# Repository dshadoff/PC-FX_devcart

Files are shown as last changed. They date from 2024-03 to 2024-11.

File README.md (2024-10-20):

# PC-FX_devcart

This is a design of a development cart for the PC-FX, based almost entirely on the
RP2040 microcontroller.

##  Current Board Revision

The current version is Ver2_RevB.
[(For the Protoype board using an Olimex RP2040-Pico30 module, please click here.)](PC_board/README_prototype.md)

The only changes from RevA to Rev B are related to schematic annotations, and a minor labelling update on the PC
Board itself, so the picture of RevA is included here.

In future, there are plans for a proper 3D printed case.

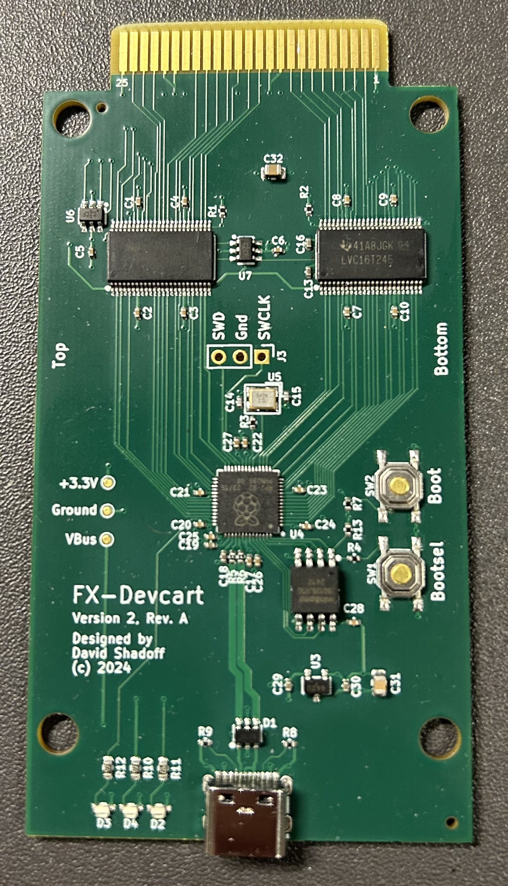
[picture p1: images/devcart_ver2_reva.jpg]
Prototype Board


## Genesis of the Project

The basis of the FX-BMP cartridge is that it consists of 128KB of memory, and the PC-FX can
actually boot from the cartridge memory under the right circumstances.

The FX-BMP memory doesn't need to be very fast - the bus access speed is cut in half when
accessing the FX-BMP range of memory. Assuming that the CPU reads the data at the rising
edge of /OE, this can be as slow as 174ns after /OE. (My design targets have been to keep this
turnaround time below 150ns).

The RP2040 has two CPU cores, and very fast GPIO access. It seemed possible to emply one
CPU core to deal with external access to the memory - emulating a SRAM bus interface - and
for the other CPU core to be used as a supervisor, allowing USB commands to read/write this
memory, downloading programs and preparing them to be booted from.

## Theory of Operation

### Signal Timing - Read

At 21MHz, you would expect the PC-FX to have a very fast bus access speed, however accesses to
the FX-BMP port are apparently clocked at half-speed (and are only 8 bits wide).

In general, bus accesses progress through the following steps for a read cycle:
- Address lines are set up
- /CE transitions low
- /OE transitions low
- The device being queried needs to ready the data, and output it onto the data bus
- /OE transitions high
- The device being queried needs to de-assert/tri-state its outputs
- /CE transitions high

While this is the normal situation, there can also be cases where the /CE line does not return to
high state before a subsequent address setup and corresponding /OE (or /WE) transition to low.

As our circuit operates at 3.3V, keep in mind that good-quality level-shifters will delay incoming
signals by roughly 5ns before they appear, and an additional 10ns on the return path, reducing the
available turnaround time for a read transaction.

Here is a visual of the actual timing of those sequences:

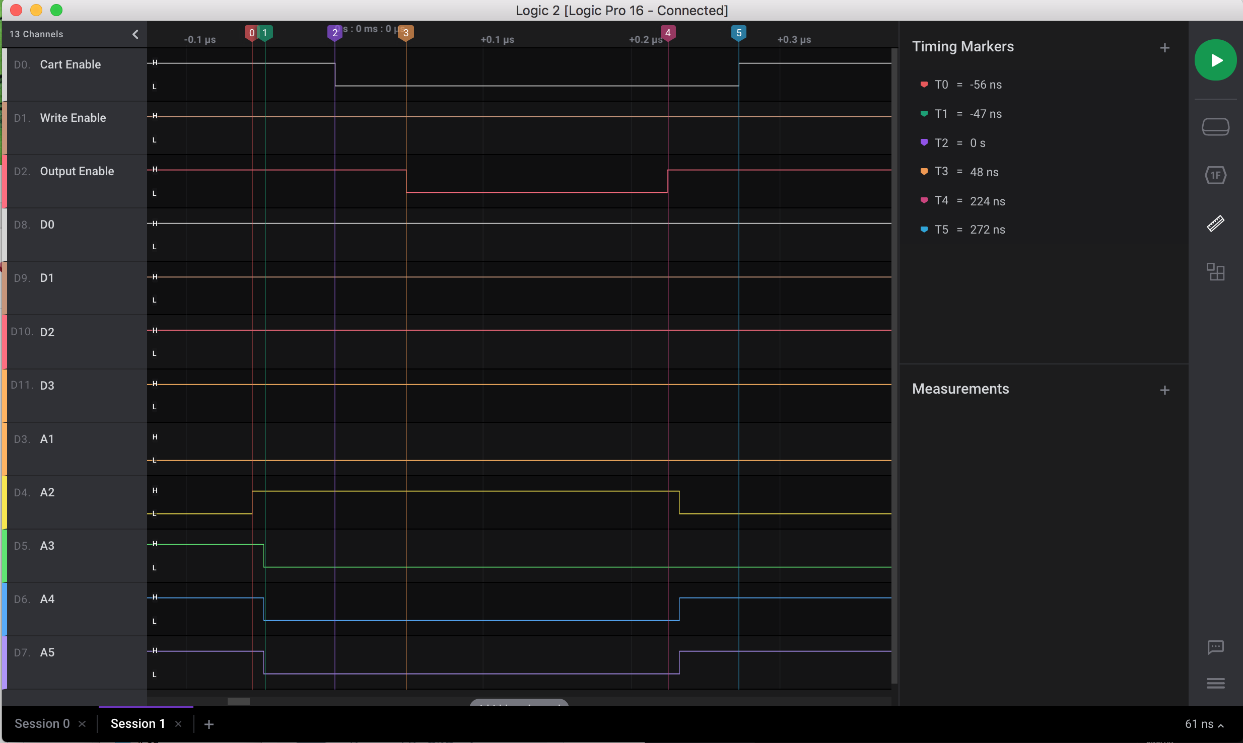
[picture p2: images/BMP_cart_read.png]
Read Cycle Timing


### Signal Timing - Write

In general, bus accesses progress through the following steps for a write cycle:
- Address lines are set up
- /CE transitions low
- /WE transitions low
- Data appears on the bus, to be written to the addressed device (not before /WE !)
- /WE transitions high
- In theory, the written-to device should latch data at this monment, but we can't react that fast, so we will latch earlier
- /CE transitions high

While this is the normal situation, there can also be cases where the /CE line does not returns to
high state before a subsequent address setup and corresponding /WE (or /OE) transition to low.

Here is a visual of the actual timing of those sequences:

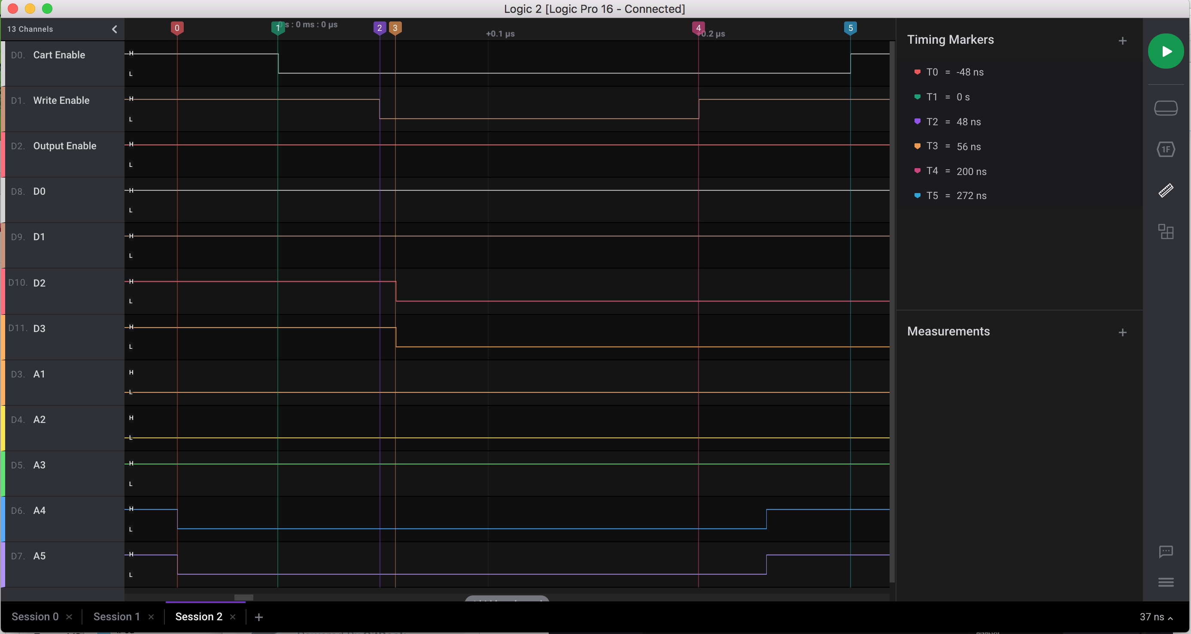
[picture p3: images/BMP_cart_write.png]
Write Cycle Timing


### GPIO Versus PIO

My original idea was to emply PIOs to manage the bus, but there are delays in crossing
between CPU and PIO (to access the CPU's memory), which hobbled performance.  However,
it turned out that the GPIO access functions are also very fast, enabling the RP2040 to
reach the apparent required speed.

### CPU Overclock

In order the reach the required speeds, the CPU is overclocked to 240MHz (the default
CPU clock speed is only 125MHz, and it is only certified to 133MHz). This might at first
sound a bit scary and possibly dangerous, but there are many cases of RP2040 examples out
in the wild and used commonly which are clocked over 250MHz (including dricing VGA and
DVI/HDMI signals), with many people finding it to work in the 400MHz range (of course,
USB and Flash access break down somewhere between 250MHz and 400MHz).

### GPIOs in USE

| GPIO | Signal |
|---|---|
| GPIO0 | D0 |
| GPIO1 | D1 |
| GPIO2 | D2 |
| GPIO3 | D3 |
| GPIO4 | D4 |
| GPIO5 | D5 |
| GPIO6 | D6 |
| GPIO7 | D7 |
| GPIO8 | A0 |
| GPIO9 | A1 |
| GPIO10 | A2 |
| GPIO11 | A3 |
| GPIO12 | A4 |
| GPIO13 | A5 |
| GPIO14 | A6 |
| GPIO15 | A7 |
| GPIO16 | A8 |
| GPIO17 | A9 |
| GPIO18 | A10 |
| GPIO19 | A11 |
| GPIO20 | A12 |
| GPIO21 | A13 |
| GPIO22 | A14 |
| GPIO23 | A15 |
| GPIO24 | A16 |
| GPIO25 | A17 |
| GPIO26 | /CE |
| GPIO27 | /OE |
| GPIO28 | /WE |

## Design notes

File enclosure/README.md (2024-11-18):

# PC-FX_devcart Enclosure

This is the 3D Print design for an enclosure for the development cart for the PC-FX.

## Introduction

Once the FX-Devcart PC board was designed and tested, an enclosure was needed in order to protect it, as well
as to align the card edge with the slot, and allow easy insertion and removal.

This design was made in two halves, both of which are described within the same design file.

##  Design Tool - Why OpenSCAD ?

While most people study 3D design in Blender or Fusion 360, I chose the OpenSCAD for my design.
The reasons are as follows:
 1. OpenSCAD is a free tool and is cross-platform.
 2. As it is code-based, it's easier for a programmer type (like myself) to become comfortable with.
 3. As it's basically code, it should be straightforward to make make edits to any portion of the design at a later date, without needing much effort.
 4. It's simple to have both halves of the case in a single design, driven by a variable - ensuring that dimensions match.

## Overview

The case design was a ground-up design using OpenSCAD 2021.01 .

As the PC Board has 3 LEDs on it next to the USB connector, the case should ideally be printed in clear resin. However,
the LED functions aren't critical to the operation of the board, so a simple 3D Print should suffice.

The case should be held together with 4 M2-13mm screws (and matching nuts).

In OpenSCAD, you can visualize different views of the model by manipulating the variables at the top of the file:
```
show_half = 1;      // 0 = bottom;     1 = top
show_board = 0;     // 0 = don't show; 1 = show 
```
You can enable either the bottom half or the top half (and render in preparation for STL output); you can also
show the PC board (an STL visualization of the board is also included, to check alignment of various features).

## Files

```
FXDev_Case.scad    - This is the master design (or 'program' if you prefer)

FX_Dev_Bottom.stl  - These files can be used in a slicer for 3D at home, or submitted to a factory like JLCPCB
FX_Dev_Top.stl

Devboard.stl       - This is an STL visualization of the PC Board (Ver2, revB), to check alignment
```

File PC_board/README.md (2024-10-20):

# PC-FX_devcart PC Board

This is the PC board design of a development cart for the PC-FX, based on the RP2040 microcontroller.

##  Current version

The current version is Ver2_RevB.
[(For the Protoype board using an Olimex RP2040-Pico30 module, please click here.)](README_prototype.md)

The only changes from RevA to Rev B are related to schematic annotations, and a minor labelling update on the PC Board itself,
so the picture of RevA is included here.

Current version

## Overview

The board design was a ground-up design for 4-layer board using KiCAD 8.0.4 .

As this was my first KiCAD design of a reasonable complexity, I was happy to receive some guidance
and schematic updates from [Regis Galland](https://github.com/rgalland).

The board is based around a RP2040 microcontroller, and its "minimal design", as shown in the Raspberry Pi
[Hardware Design With RP2040 Design Guide](https://datasheets.raspberrypi.com/rp2040/hardware-design-with-rp2040.pdf).

The bus decoding was based on my earlier work with the [PC-FX_nvBMP board](https://github.com/pcfx-devel/PC-FX-NVBMP).

The 3.3V power is not derived from PC-FX's power: The RP2040 is powered from the USB host, and an on-board
3.3V regulator provides the 3.3V rail for the module and the 3.3V side of the level-shifters.

Only the 5V side of the level-shifters is supplied by the PC-FX (however, they share a common ground).

This means that:
 1) The FX-devcart board will not function correctly when not connected to USB, as this is the main power source.
 2) The FX-devcart can be programmed while inserted into the PC-FX, while the PC-FX is not turned on - this is
important for the ability to "boot" code from teh FX-devcart

## Files

KiCAD was used for designing the board, and all design files are included.
(FX-Dev_Ver2_revB.zip is a KiCAD Project archive, including all relevant footprints and datasheets).

In order to manufacture the board, the key files are in the "production" subfolder:
 - Gerber files are supplied in the relevant 'Gerbersi_xxx.zip' file.
 - bom.csv is the bill-of-materials file, prepared in the format for JLCPCB's assembly service
 - positions.csv is the pick-and-place part positioning file, prepared in the format for JLCPCB's assembly service

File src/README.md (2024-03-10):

# PC-FX_Devcart source

This section contains all the code related to the PC-FX devcart, divided into three sections:

### PC

This contains small program written in Python which will interact with the developmnet cart,
ending/receiving backup memory files, preparing programs to be bootable software, or reading
from the FIFO port.

### RP2040

This section contains the program that runs on the development cartridge's microcontroller,
and interacts with both the I/O bus and the USB port.

### PC-FX

This is sample code to include in your PC-FX project, in order to use the FIFO port.
The sample file is intermingled comments and code snippets which explain what components
are needed to intiializae and to interact with the FIFO port (but not a sample program).

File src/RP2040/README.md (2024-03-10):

# PC-FX_Devcart source - RP2040

This section contains the program that runs on the development cartridge's microcontroller,
and interacts with both the I/O bus and the USB port.

# Folders Overview

## boards

Developmnet board capabilities are indicated by a '.h' file describing each board's capabilities,
and are generally found in the {pico-sdk}/src/boards/include/boards directory in the piso-sdk tree.

The original Pico board actually doesn't expose all of the GPIOs, and dedicates some of the GPIOs
to use in different purposes.  As this board needs essentially all GPIOs to be employed for memory
addressing, a board which revealed all 30 GPIOs was needed - and a board description file (the '.h'
file mentioned above) to match.

For the prototype, I ended up using the Olimex RP2040-PICO30 board, which doesn't have its own board
definition file, so I altered an existing file to create one.  This is the 'olimex_rp2040-pico30.h'
file in the 'boards' folder.

## cart

This folder contains the source code for the development cart.
The 'RELEASE' folder includes a '.uf2' file which can be deployed directly on the cart.

## test_device

Through the process of initial build and responsiveness testing, I used 2 Raspberry Pi Pico
boards to test each other (but with a more limited address space).

This 'test_device' was set up to send the signals (with approximate timings) to the device under test,
in order to measure the response timing and accuracy of the results.  GPIOs 0 through 22, as well as
26, 27, and 28 on the test device were connected to the same GPIOs on the device under test, with logic
state analyzer set up to measure the timing of several data lines, several address lines, and all control
lines, in order to validate timing.

# Development Chain & Tools

This was all written using pico-sdk version 1.5.0 and the matching/included version of TinyUSB.
This may be updated for later revisions as they become available, especially if useful new features
become available.

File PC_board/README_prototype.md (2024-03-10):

# PC-FX_devcart PC Board

This is the PC board design of a development cart for the PC-FX, based on the RP2040 microcontroller.

##  Prototype Board

This is the initial board, using an Olimex RP2040-Pico30 board, and some nylon standoffs
(5mm on bottom, 7mm on top).  In future, there will a new design for the board which won't
need a daughterboard, and will have plans for a proper 3D printed case.

Prototype Board

## Overview

The overall board design was based on my earlier PC-FX_nvBMP board using EAGLE.

The prototype board uses the Olimex RP2040-Pico30 board, because it is an easy-to-use,
self-contained module which also exposes all 30 of the GPIOs (which most boards don't do).

An optional 3x10 right-angle header can be mounted on the board, for use with a logic state
analyzer, to monitor the relevant bus signals (to/from the RP2040 module).  Note that there
is likely and additional 5ns latency between the PC-FX and these signals - both inbound and
outbound - due to the level-shifters.  Signals are marked in silkscreen on the board.

One major difference from the PC-FX_nvBMP board, is that the 3.3V power is not derived from
PC-FX's power: The RP2040 module is powered from the USB host, and an on-board 3.3V regulator
provides the 3.3V rail for the module and the 3.3V side of the level-shifters.  Only the 5V side
of the level-shifters is supplied by the PC-FX (however, they share a common ground).

## Files

EAGLE was used for the prototype board, and all design files are included.

Gerber files are supplied in the relevant 'xxx_gerbers.zip' file.

If you would like to use JLCPCB's SMT Assembly service, a 'BOM.csv' (BOM/bill-of-materials)
file and 'assembly.csv' (CPL/component positioning and layout) files are also included.

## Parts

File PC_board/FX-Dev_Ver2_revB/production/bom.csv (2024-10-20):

Designator | Footprint | Quantity | Value | LCSC Part #
C1, C10, C17, C2, C20, C21, C22, C23, C24, C25, C26, C27, C28, C3, C4, C5, C6, C7, C8, C9 | 0402 | 20 | 100nF | C307331
C13, C16, C18, C19, C29, C30 | 0402 | 6 | 1uF | C52923
C14, C15 | 0402 | 2 | 15pF | C3870187
C31, C32 | 0805 | 2 | 10uF | C15850
D1 | SOT-23-6_L2.9-W1.6-P0.95-LS2.8-BL | 1 | USBLC6-2SC6 | C7519
D2 | LED-SMD_L1.7-W0.6-RD | 1 | LTST-S270KGKT | C125113
D3 | LED-SMD_L1.7-W0.6-RD | 1 | LTST-S270KSKT | C133119
D4 | LED-SMD_L1.7-W0.6-RD | 1 | LTST-S270KRKT | C125114
R1, R2 | 0402 | 2 | 47K | C25792
R10, R11, R12 | 0603 | 3 | 4.7K | C23162
R13, R7 | 0402 | 2 | 10K | C25744
R3 | 0402 | 1 | 1K | C11702
R4 | 0402 | 1 | 100 | C25076
R5, R6 | 0402 | 2 | 27R | C542952
R8, R9 | 0402 | 2 | 5.1K | C25905
SW1, SW2 | SW-SMD_4P-L5.1-W5.1-P3.70-LS6.5-TL-2 | 2 | TS-1187A-B-A-B | C318884
U1, U2 | TSSOP-48_L12.6-W6.2-P0.50-LS8.1-BL | 2 | SN74LVC16T245DGGR | C148170
U3 | SOT-23-3_L2.9-W1.6-P1.90-LS2.8-BR | 1 | XC6206P332MR | C5446
U4 | LQFN-56_L7.0-W7.0-P0.4-EP | 1 | RP2040 | C2040
U5 | CRYSTAL-SMD_4P-L3.2-W2.5-BL | 1 | ABM8-272-T3_C20625731 | C20625731
U6, U7 | SOT-23-6_L2.9-W1.6-P0.95-LS2.8-BR | 2 | SN74LVC1G332DBVR | C43368
U8 | SOIC-8_L5.3-W5.3-P1.27-LS8.0-BL | 1 | W25Q128JVSIQTR | C97521
USBC2 | USB-C_SMD-TYPE-C-31-M-12 | 1 | TYPE-C-31-M-12 | C165948

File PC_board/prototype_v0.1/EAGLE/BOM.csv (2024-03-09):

Qty | Designator | Footprint | Comment | LCSC Part # (optional) | Description (optional)
10 | C1, C2, C3, C4, C5, C6, C7, C8, C9, C11 | C0402 | 100nF 16V | C1525 | Samsung CL05B104KO5NNNC 100nF 16V 0402
2 | C12, C13 | C0402 | 1uF 25V | C52923 | Samsung CL05A105KA5NQNC 1uF 25V 0402
1 | R1 | R0402 | 47K | C25741 | 62.5mW Thick Film Resistors 50V ±100ppm/_ ±1% -55_~+155_ 100kΩ 0402 Chip Resistor - Surface Mount ROHS
2 | IC3, IC4 | TSSOP-48 | 74LVC16T245DGGR | C148170 | Texas Instruments 74LVC16T245DGGR, Dual, Bus Transceiver, 16-Bit Non-Inverting LVTTL, 1.65 5.5 V, 48-Pin TSSOP
2 | IC1, IC2 | SOT-23-6 | 74LVC1G332DBVR | C43368 | Texas Instruments 74LVC1G332DBVR, 3-Input OR Logic Gate, 1.65 5.5 V, 6-Pin SOT-23

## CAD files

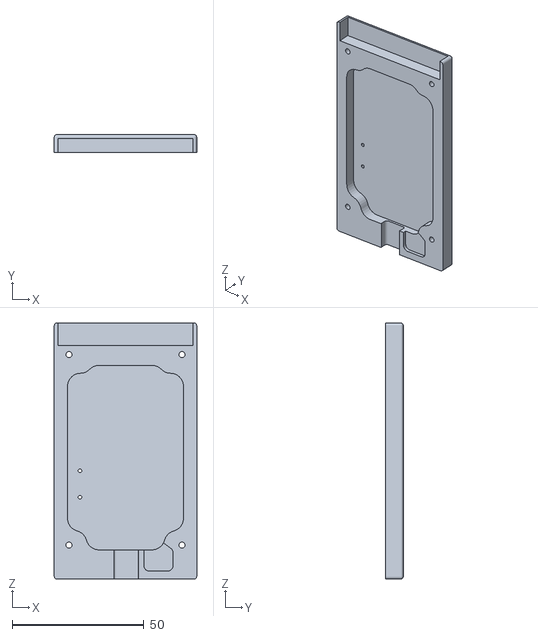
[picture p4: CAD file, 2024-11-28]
enclosure/FX_Dev_Top.stl
54.0 x 6.75 x 97.0

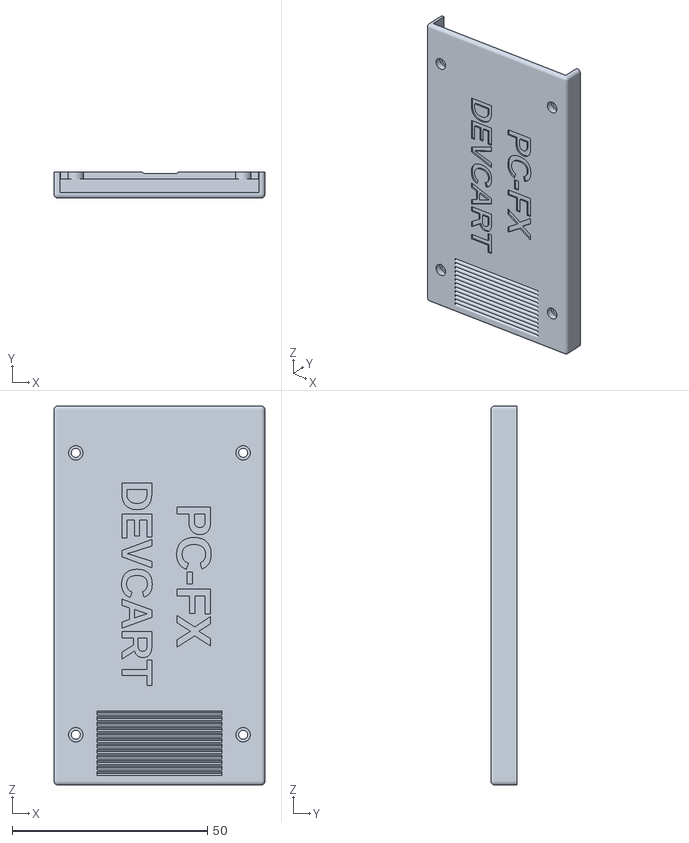
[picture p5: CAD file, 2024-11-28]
enclosure/FX_Dev_Bottom.stl
54.0 x 6.75 x 97.0

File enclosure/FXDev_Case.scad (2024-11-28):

//
// PC-FX dev cartridge shell
//
// (c) 2024,  David Shadoff
//

// definitions of what to show
// Please adjust these
//
// In order to create a full shell, you will need to run STL once
// with 'show_half = 0', and once with 'show_half = 1'
//
show_half = 1;      // 0 = bottom;     1 = top
show_board = 0;     // 0 = don't show; 1 = show


$fn=30;

// case outer dimensions
case_len = 97;
case_width = 54;
case_thick = 13.5;
mink_edge = 1;

// case card-edge dimensions
end_hole_deep = 8.5;
end_edge_thick = 1.5;

// PC board dimensions
board_width = 50;
board_edge_tol = 0.3;
tray_width = board_width+(2*board_edge_tol);
board_thick = 1.6;
board_thick_tol = 0.2;
usb_edge = 1.5;
overshoot = 0.1;

//support cylinders
cyl_outer_rad = (4.0/2);  // 4.0 mm (support hole in PC board is actually 4.4mm
cyl_inner_rad = (2.3/2);  // 2.0 mm (for ?? screw shaft)
screwhead_depth = 2.0;
screwhead_rad = (3.7/2);
nuthead_depth = 1.5;
nuthead_rad = (4.7/2);

// relative to board
bottom_z = 11.3654;
top_z = 83.509;
left_x = 46.4086;
right_x = 3.5814;

//Text
text_size = 9;
text_size_2 = 8;
text_depth = 0.5;

// bottom_well
bottom_well_depth = 3.5;

// top square
hollow_1_width = 44;
hollow_1_thick = 3.5;
hollow_1_bottom = 16;
hollow_1_len = 65;

//pinhole
pinhole_radius = (1.4/2);

// grip
grip_length = 32;



module support_cylinder(x_pos, y_pos) {     // additive, meant for bottom side
    translate([((case_width - board_width)/2)+x_pos, (case_thick/2), (usb_edge+y_pos)]) {
      rotate([90, 0,0])
      cylinder(h=(case_thick/2), r1=cyl_outer_rad, r2=cyl_outer_rad);
    }
}

module screw_shaft(x_pos, y_pos) {          // subtractive, applies to both sides
    translate([((case_width - board_width)/2)+x_pos, (case_thick+overshoot), (usb_edge+y_pos)]) {
      rotate([90, 0,0])
      cylinder(h=(case_thick+(overshoot*2)), r1=cyl_inner_rad, r2=cyl_inner_rad);
    }
}

module screwhead_sink(x_pos, y_pos) {       // subtractive, applies to bottom side
    translate([((case_width - board_width)/2)+x_pos, screwhead_depth, (usb_edge+y_pos)]) {
      rotate([90, 0,0])
      cylinder(h=screwhead_depth+overshoot, r1=screwhead_rad, r2=screwhead_rad);
    }
}

module nuthead_sink(x_pos, y_pos) {         // subtractive, applies to top side
    translate([((case_width - board_width)/2)+x_pos, (case_thick+overshoot), (usb_edge+y_pos)]) {
      rotate([90, 0,0])
      //TODO: make this into hexagonal well
      cylinder(h=nuthead_depth+overshoot, r1=nuthead_rad, r2=nuthead_rad, $fn=6);
    }
}

module reset_pinhole(x_pos, y_pos) {
    translate([x_pos,(case_thick/2)-overshoot, y_pos])
        rotate([-90,0,0])
            cylinder(h = (case_thick/2)+(overshoot*2), r = pinhole_radius);
}

module grip_inset(length, iterations) {
    translate([length,0,0])
    rotate([0,-90,0])
    linear_extrude(length) {
        translate([0,-0.9])
        rotate(-45)
        union() {
            for(i= [0:1:iterations] ) {
                translate([i,i])
                square([2,2]);
            }
        }
    }
}

// This is the main "program" for the shell
//
difference() {
    union() {
        difference() {

        // overall outer shape
            translate([mink_edge,mink_edge,mink_edge])
            minkowski()
            {
               cube([(case_width-(2*mink_edge)),(case_thick-(2*mink_edge)),(case_len-(2*mink_edge))]);
               sphere(r=mink_edge,$fn=50);
            }

            // hollow-out at card-edge
            translate([(end_edge_thick), (end_edge_thick), (case_len-end_hole_deep)])
                cube( [ (case_width-(2*end_edge_thick)),(case_thick-(2*end_edge_thick)), end_hole_deep+end_edge_thick ] );

            // if bottom half, cut off top half
            if (show_half == 0) {
                translate([-overshoot, (case_thick/2), -overshoot]) {
                    cube([(case_width+(2*overshoot)), ((case_thick/2)+(2*overshoot)), (case_len+(2*overshoot))]);
                }

                // cut out tray for PC board
                translate([(case_width - tray_width)/2, (case_thick/2)-(board_thick+board_thick_tol), (usb_edge-board_edge_tol)]) {
                    cube([tray_width,(board_thick+(2*board_thick_tol)),case_len]);
                }

                // cut out additional unnecessary well below PC board
                translate([((case_width - 38)/2)+(38/2), (case_thick/2)-board_thick-bottom_well_depth+(2*overshoot),(60/2)+18]) {
                    rotate([-90, 0,0]) {
                        linear_extrude(bottom_well_depth+overshoot) {
                            offset(r = -5) {
                                minkowski() {
                                    union() {
                                        square([30,50], center=true);
                                        translate([-10,-28])
                                        square([20,56]);
                                    }
                                    circle(10);
                                }
                            }
                        }
                    }
                }
            }
            else {
                // if top half, cut off bottom
                translate([-overshoot, -overshoot, -overshoot]) {
                    cube([(case_width+(2*overshoot)), ((case_thick/2)+(overshoot)), (case_len+(2*overshoot))]);
                }

                // Subtract bubble for electronic components (top half only)
                translate([((case_width - 38)/2)+(38/2), (case_thick/2)-overshoot,(60/2)+18]) {
                    rotate([-90, 0,0]) {
                        linear_extrude(4.5+overshoot) {
                            offset(r = -5) {
                                minkowski() {
                                    union() {
                                        square([34,50], center=true);
                                        translate([-10,-28])
                                        square([20,60]);
                                    }
                                    circle(10);
                                }
                            }
                        }
                    }
                }

                // Subtract LED well (top half only)
                translate([(case_width - 18), (case_thick/2)-overshoot, 10]) {
                    rotate([-90, 0,0]) {
                        linear_extrude(1.5) {
                            minkowski() {
                               polygon([[0,-2],[3,-3],[7,0],[7,5],[0,5]]);
                                circle(2);
                            }
                        }
                    }
                }   
            }
        }
 
        // add support cylinders (bottom only)
        if (show_half == 0) {
            support_cylinder(left_x, bottom_z);     // bottom left
            support_cylinder(right_x, bottom_z);    // bottom right
            support_cylinder(left_x, top_z);        // top left
            support_cylinder(right_x, top_z);       // top right
        }
    }
    
    // subtract support cylinder screw shafts (both halves)
    screw_shaft(left_x, bottom_z);                  // bottom left
    screw_shaft(right_x, bottom_z);                 // bottom right
    screw_shaft(left_x, top_z);                     // top left
    screw_shaft(right_x, top_z);                    // top right

    // subtract support screwhead wells (bottom only)
    if (show_half == 0) {
        screwhead_sink(left_x, bottom_z);           // bottom left
        screwhead_sink(right_x, bottom_z);          // bottom right
        screwhead_sink(left_x, top_z);              // top left
        screwhead_sink(right_x, top_z);             // top right
    }
    else {
    // subtract support nuts hexagon wells (top only)
        nuthead_sink(left_x, bottom_z);             // bottom left
        nuthead_sink(right_x, bottom_z);            // bottom right
        nuthead_sink(left_x, top_z);                // top left
        nuthead_sink(right_x, top_z);               // top right
    }

    // Subtract reset button pinholes (top half only)
    if (show_half == 1) {
        reset_pinhole(9.75, 41);
        reset_pinhole(9.75, 31);
    }


    // Subtract USB hole (both halves)
    translate([23.5,(case_thick/2)+0.5, -overshoot]) {
        linear_extrude(12) {
            minkowski() {            
                square([7.5,2]);
                circle(1);
            }
        }
    }

    // Subtract grip ridges - both halves, but different position for each
    if (show_half == 1) {
        translate([((case_width-grip_length)/2), case_thick, 1.5]) {
            mirror([0,1,0]) {
                grip_inset(grip_length, 11);

            }
        }
    }
    else {
        translate([((case_width-grip_length)/2), 0, 1.5]) {
            grip_inset(grip_length, 11);
        }
    }
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

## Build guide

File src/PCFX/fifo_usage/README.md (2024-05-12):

# PC-FX_Devcart source - PC-FX

This is sample code to include in your PC-FX project, in order to use the FIFO port.
The sample file is intermingled comments and code snippets which explain what components
are needed to intiialize and to interact with the FIFO port (but not a sample program).

# Program Files Overview

fifoport.s - This is a set of functions in V810 assembly which access the actual hardware memory
locations directly\
fifoport.h - This should be included in your program in order to make use of the FIFO functions above\
sample.c - This is a couple of sample functions to use in your program, as well as a reminder to
unlock/allow access to the BMP memory region

## Development Chain & Tools

This was written using a version of gcc for V810 processor, with 'pcfxtools' which assist in
building executables for PC-FX, and 'liberis' which is a library of functions targetting the PC-FX.

These can be found here:\
[https://github.com/jbrandwood/v810-gcc](https://github.com/jbrandwood/v810-gcc)\
[https://github.com/jbrandwood/pcfxtools](https://github.com/jbrandwood/pcfxtools)\
[https://github.com/jbrandwood/liberis](https://github.com/jbrandwood/liberis)

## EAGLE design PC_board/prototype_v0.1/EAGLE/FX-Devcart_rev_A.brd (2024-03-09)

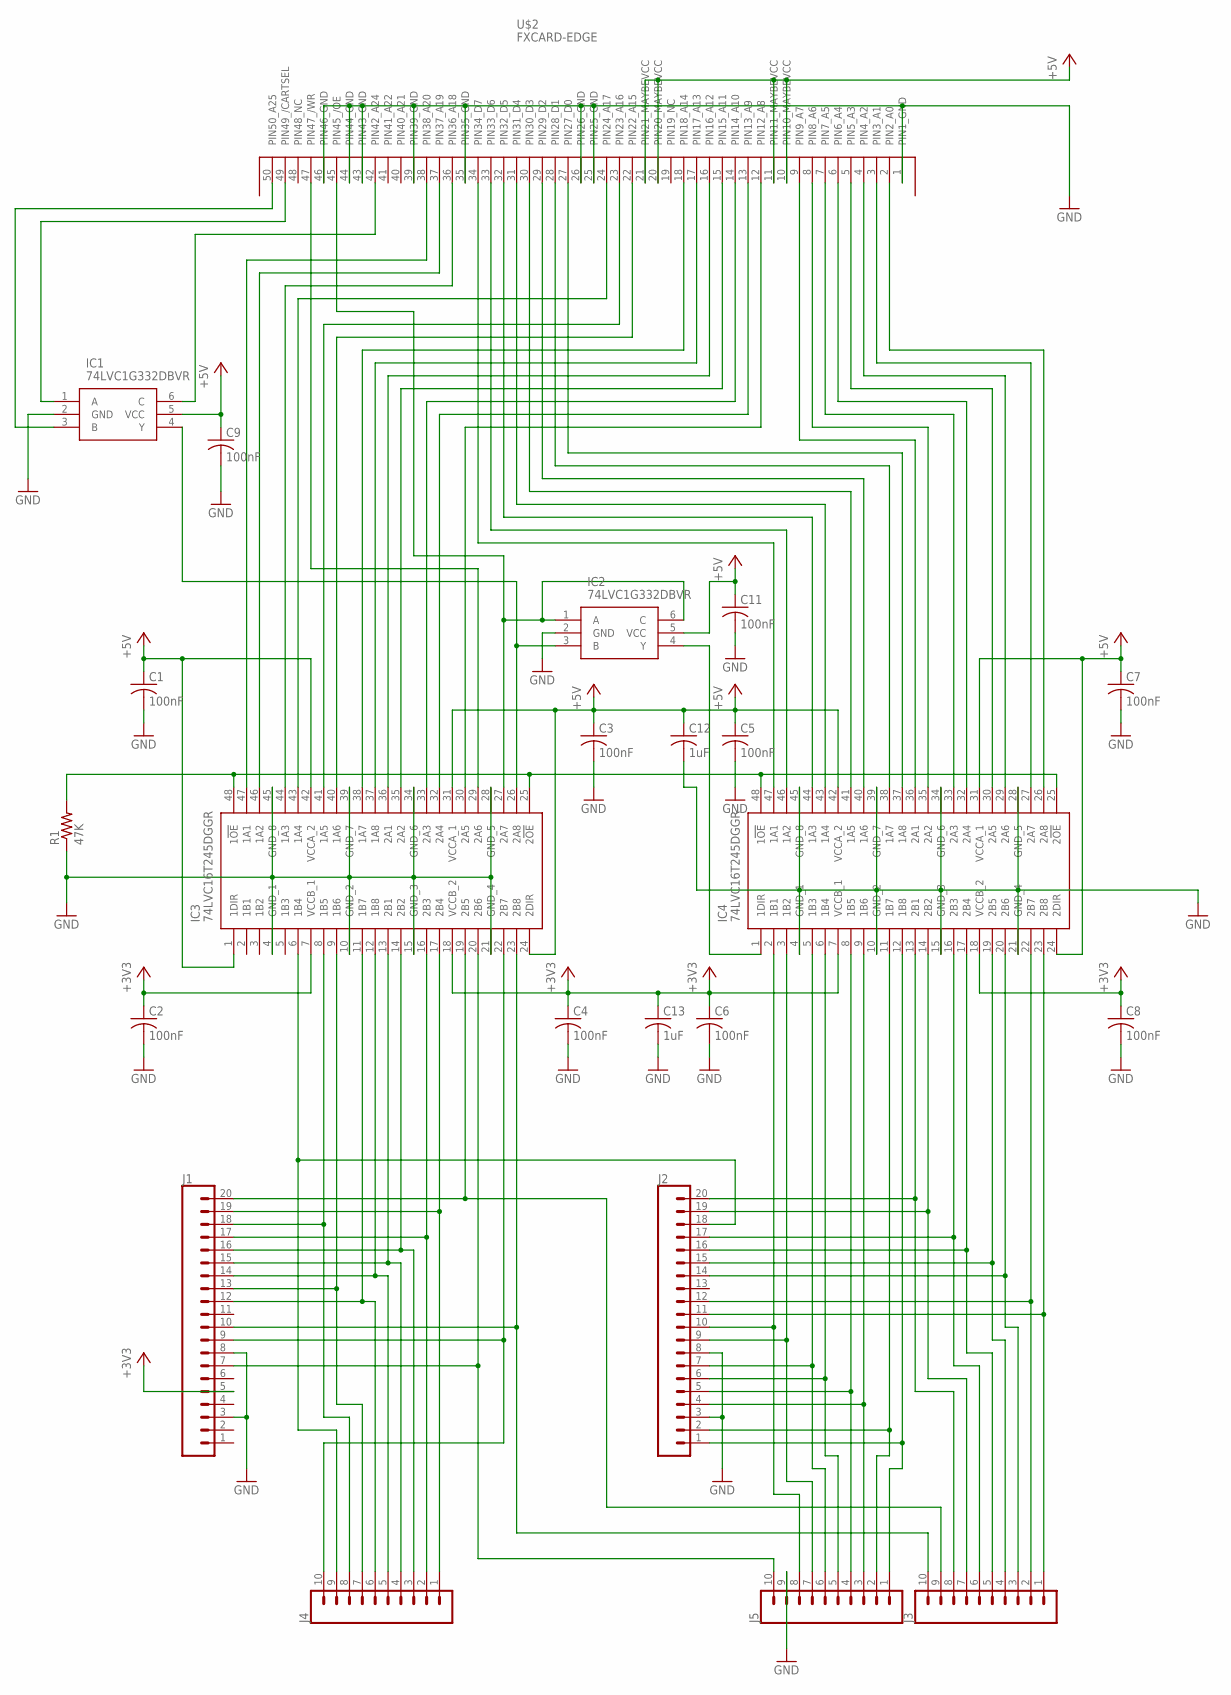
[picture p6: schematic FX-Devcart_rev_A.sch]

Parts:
C1, C2, C3, C4, C5, C6, C7, C8, C9, C11: 100nF; C0402
C12, C13: 1uF; C0402
IC1, IC2: 74LVC1G332DBVR; SOT95P280X145-6N
IC3, IC4: 74LVC16T245DGGR; SOP50P810X120-48N
J1, J2: CONN_20NOSILK; 1X20_NOSILK
J3, J4, J5: CONN_10NO_SILK_PTH_FEMALE; 1X10_NO_SILK
R1: 47K; R0402
U$2: FXCARD-EDGE

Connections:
+3V3: C2.1, C4.1, C6.1, C8.1, C13.1, IC3.7 (VCCB_1), IC3.18 (VCCB_2), IC4.7 (VCCB_1), IC4.18 (VCCB_2), J1.5
+5V: C1.1, C3.1, C5.1, C7.1, C9.1, C11.1, C12.1, IC1.5 (VCC), IC2.5 (VCC), IC3.1 (1DIR), IC3.24 (2DIR), IC3.31 (VCCA_1), IC3.42 (VCCA_2), IC4.24 (2DIR), IC4.31 (VCCA_1), IC4.42 (VCCA_2), U$2.10 (PIN10_MAYBEVCC), U$2.11 (PIN11_MAYBEVCC), U$2.20 (PIN20_MAYBEVCC), U$2.21 (PIN21_MAYBEVCC)
GND: C1.2, C2.2, C3.2, C4.2, C5.2, C6.2, C7.2, C8.2, C9.2, C11.2, C12.2, C13.2, IC1.2 (GND), IC2.2 (GND), IC3.4 (GND_1), IC3.10 (GND_2), IC3.15 (GND_3), IC3.21 (GND_4), IC3.28 (GND_5), IC3.34 (GND_6), IC3.39 (GND_7), IC3.45 (GND_8), IC4.4 (GND_1), IC4.10 (GND_2), IC4.15 (GND_3), IC4.21 (GND_4), IC4.28 (GND_5), IC4.34 (GND_6), IC4.39 (GND_7), IC4.45 (GND_8), J1.3, J1.8, J2.3, J2.8, J5.9, R1.1, U$2.1 (PIN1_GND), U$2.25 (PIN25_GND), U$2.26 (PIN26_GND), U$2.35 (PIN35_GND), U$2.39 (PIN39_GND), U$2.43 (PIN43_GND), U$2.44 (PIN44_GND), U$2.46 (PIN46_GND)
unnamed: IC4.37 (1A8), U$2.27 (PIN27_D0)
unnamed: IC4.38 (1A7), U$2.28 (PIN28_D1)
unnamed: IC4.40 (1A6), U$2.29 (PIN29_D2)
unnamed: IC4.41 (1A5), U$2.30 (PIN30_D3)
unnamed: IC4.43 (1A4), U$2.31 (PIN31_D4)
unnamed: IC4.44 (1A3), U$2.32 (PIN32_D5)
unnamed: IC4.46 (1A2), U$2.33 (PIN33_D6)
unnamed: IC4.47 (1A1), U$2.34 (PIN34_D7)
unnamed: IC4.26 (2A8), U$2.2 (PIN2_A0)
unnamed: IC4.27 (2A7), U$2.3 (PIN3_A1)
unnamed: IC4.29 (2A6), U$2.4 (PIN4_A2)
unnamed: IC4.30 (2A5), U$2.5 (PIN5_A3)
unnamed: IC4.33 (2A3), U$2.7 (PIN7_A5)
unnamed: IC3.43 (1A4), U$2.24 (PIN24_A17)
unnamed: IC4.35 (2A2), U$2.8 (PIN8_A6)
unnamed: IC4.36 (2A1), U$2.9 (PIN9_A7)
unnamed: IC4.32 (2A4), U$2.6 (PIN6_A4)
unnamed: IC3.44 (1A3), U$2.36 (PIN36_A18)
unnamed: IC3.46 (1A2), U$2.37 (PIN37_A19)
unnamed: IC3.47 (1A1), U$2.38 (PIN38_A20)
unnamed: IC1.4 (Y), IC2.3 (B), IC3.26 (2A8)
unnamed: IC3.25 (2!OE), IC3.48 (1!OE), IC4.25 (2!OE), IC4.48 (1!OE), R1.2
unnamed: IC4.23 (2B8), J2.11, J3.1
unnamed: IC4.22 (2B7), J2.12, J3.2
unnamed: IC4.20 (2B6), J2.14, J3.3
unnamed: IC2.4 (Y), IC4.1 (1DIR)
unnamed: IC4.19 (2B5), J2.15, J3.4
unnamed: IC4.17 (2B4), J2.16, J3.5
unnamed: IC4.16 (2B3), J2.17, J3.6
unnamed: IC4.14 (2B2), J2.19, J3.7
unnamed: IC4.13 (2B1), J2.20, J3.8
unnamed: IC4.12 (1B8), J2.1, J5.1
unnamed: IC3.30 (2A5), U$2.12 (PIN12_A8)
unnamed: IC3.32 (2A4), U$2.13 (PIN13_A9)
unnamed: IC3.33 (2A3), U$2.14 (PIN14_A10)
unnamed: IC3.35 (2A2), U$2.15 (PIN15_A11)
unnamed: IC3.36 (2A1), U$2.16 (PIN16_A12)
unnamed: IC3.37 (1A8), U$2.17 (PIN17_A13)
unnamed: IC3.38 (1A7), U$2.18 (PIN18_A14)
unnamed: IC3.40 (1A6), U$2.22 (PIN22_A15)
unnamed: IC3.41 (1A5), U$2.23 (PIN23_A16)
unnamed: IC3.29 (2A6), U$2.47 (PIN47_/WR)
unnamed: IC2.1 (A), IC2.6 (C), IC3.27 (2A7), U$2.45 (PIN45_/OE)
unnamed: IC1.3 (B), U$2.50 (PIN50_A25)
unnamed: IC1.1 (A), U$2.49 (PIN49_/CARTSEL)
unnamed: IC1.6 (C), U$2.42 (PIN42_A24)
unnamed: IC4.11 (1B7), J2.2, J5.2
unnamed: IC4.9 (1B6), J2.4, J5.3
unnamed: IC4.8 (1B5), J2.5, J5.4
unnamed: IC4.6 (1B4), J2.6, J5.5
unnamed: IC4.5 (1B3), J2.7, J5.6
unnamed: IC4.3 (1B2), J2.9, J5.7
unnamed: IC3.20 (2B6), J1.7, J5.10
unnamed: IC3.19 (2B5), J1.20, J3.9
unnamed: IC3.17 (2B4), J1.19, J4.1
unnamed: IC3.16 (2B3), J1.17, J4.2
unnamed: IC3.14 (2B2), J1.16, J4.3
unnamed: IC3.13 (2B1), J1.15, J4.4
unnamed: IC3.12 (1B8), J1.14, J4.5
unnamed: IC3.11 (1B7), J1.12, J4.6
unnamed: IC3.9 (1B6), J1.13, J4.7
unnamed: IC3.8 (1B5), J1.18, J4.8
unnamed: IC3.6 (1B4), J2.18, J4.9
unnamed: IC3.22 (2B7), J1.9, J4.10
unnamed: IC3.23 (2B8), J1.10, J3.10
unnamed: IC4.2 (1B1), J2.10, J5.8

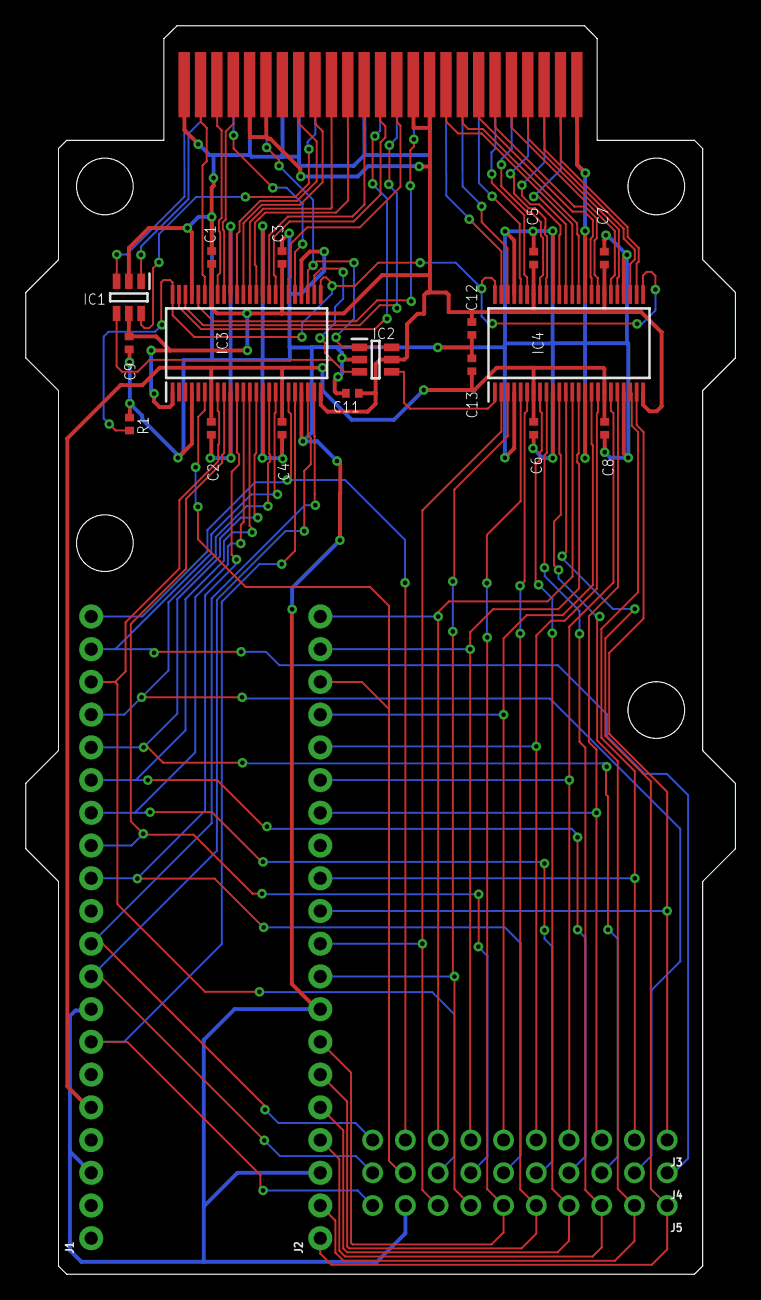
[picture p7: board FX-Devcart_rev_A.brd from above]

Board: 2 copper layers, 55.1 x 96.9 mm, 23 parts (0 on the bottom side), 69 nets.

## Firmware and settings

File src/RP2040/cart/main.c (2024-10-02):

/*
 * Copyright (c) 2020 Raspberry Pi (Trading) Ltd.
 *
 * SPDX-License-Identifier: BSD-3-Clause
 */

//#define TEST_BUILD



#include <stdio.h>
#include <string.h>

#include "pico/stdlib.h"
#include "pico/multicore.h"
#include "hardware/uart.h"
#include "hardware/clocks.h"
#include "hardware/vreg.h"

// These "extern inline" definitions are strong hints to
// actually inline these functions (which would otherwise
// be left up to the compiler to decide)
//
extern inline uint32_t gpio_get_all(void) __attribute__((always_inline));
extern inline void gpio_put_masked(uint32_t mask, uint32_t value) __attribute__((always_inline));
extern inline void gpio_set_dir_masked(uint32_t mask, uint32_t value) __attribute__((always_inline));

//--------------------------------------------------------------------+
// MACRO CONSTANT TYPEDEF PROTYPES
//--------------------------------------------------------------------+


#define UART_ID uart0
#define BAUD_RATE 115200

// Use USB UART
//
//  We are using pins 0 and 1, but see the GPIO function select table in the
//  datasheet for information on which other pins can be used.
// #define UART_TX_PIN 0
// #define UART_RX_PIN 1


//
// USB COM port commmand definitions:
//
#define  CMD_DUMP      '?'    // dump 256 bytes of hex
#define  CMD_DUMPALL   '!'    // dump 16384+16 bytes of hex
#define  CMD_GETFIFO   '/'    // read FIFO

#define  CMD_BOOT             'B'    // Boot program (B is followed by 4 bytes size, then program)
#define  CMD_BOOT_BLOCK_CONT  '1'    // Boot program load a block (add prev length to start; confirm
                                     // with '1' to indicate continuation)
                                     // '1' is followed by 4 bytes size, then program
#define  CMD_BOOT_BLOCK_FINAL '2'    // Boot program load final block (add prev length to start;
                                     // confirm with '2' to indicate completion)
                                     // '2' is followed by 4 bytes size, then program
#define  CMD_WRITE128K        'W'    // write all 128KB of memory (128KB of data follows)
#define  CMD_READ128K         'R'    // read all 128KB of memory (128KB of data is returned)


//
// hardware-level definitions:
//
#define DATA0_PIN      0      // use GPIO 0-7  for data
#define ADDR0_PIN      8      // use GPIO 8-25 for address
#define CE_PIN        26      // use GPIO 26 for Chip Enable
#define OE_PIN        27      // use GPIO 27 for Output Enable
#define WE_PIN        28      // use GPIO 28 for Write Enable

#define READ_BITMASK  ((1 << CE_PIN) | (1 << OE_PIN))
#define WRITE_BITMASK ((1 << CE_PIN) | (1 << WE_PIN))



#ifdef TEST_BUILD
#define GPIO_TESTSIZE
#else
#define GPIO_FULLSIZE
#endif

#ifdef GPIO_FULLSIZE

#define ARRAY_SIZE        131072
#define GPIO_MASK_ADDR    0x03FFFF00 // ultimately, 128KB + port space
#define GPIO_ADDR_THRESH  0x00020000 // ultimately, port space threshold
#define GPIO_PORT_DATA    0x00020002
#define GPIO_PORT_CONTROL 0x00020001

#else                   // else, these are the TESTSIZE variables

#define ARRAY_SIZE        32768
#define GPIO_MASK_ADDR    0x007FFF00 // currently, 16KB + port space
#define GPIO_ADDR_THRESH  0x00004000 // currently, port space threshold
#define GPIO_PORT_DATA    0x00004002
#define GPIO_PORT_CONTROL 0x00004001

#endif

#define GPIO_ADDR_SHIFT   8              // since A0 = GPIO8, this is the shift amount

#define GPIO_MASK_DATA    0x000000FF     // bottom GPIOs (GPIO0-7) used for data

#define VALUE_INV_ADDR    0xFF           // 'floating' lines. Should be 0xFF, but 0xAA during test.


// PC-FX Code Boot particulars:
//
#define CODE_BMP_OFFSET      0x0400
#define FX_EXECUTION_ADDR    0x8000

#define FX_CONFIRMATION      0x0027      // address to confirm that data write is complete (and/or final)
#define FX_BOOT_OFFSET       0x0030      // Offset from start of cartridge memory (data to transfer to RAM)
#define FX_BOOT_LOADADDR     0x0034      // PCFX main memory location to transfer the memory into
#define FX_BOOT_NUMBYTES     0x0038      // Number of bytes to copy to target memory location
#define FX_BOOT_EXEC         0x003C      // After load completes, this holds the execution addr

#define FX_WRITE_DONE        '1'         // confirm memory write complete; more to come
#define FX_WRITE_FINISHED    '2'         // confirm memory write complete; no more to come


// PC-FX control port flag bits:
#define  FIFO_CTRL_DO_NOT_WRITE  0x80    // bit 7 = HIGH when queue full (i.e. do not write)
#define  FIFO_CTRL_DO_NOT_READ   0x40    // bit 6 = HIGH when queue empty (i.e. do not read)

#define FIFO_SIZE        1024
#define FIFO_SIZE_MASK   0x3FF



// Memory array variables:
//
volatile uint8_t  mem_array[ARRAY_SIZE];


// FIFO port variables:
//
volatile uint8_t  fifo_from_pcfx[FIFO_SIZE];
volatile uint8_t  fifo_to_pcfx[FIFO_SIZE];

volatile int      from_pcfx_tail = 0; // outbound data to PC
volatile int      from_pcfx_head = 0;

volatile int      to_pcfx_tail = 0;   // tail points at location to read next data from
volatile int      to_pcfx_head = 0;   // head points at location to write next data to

volatile uint8_t  control  = FIFO_CTRL_DO_NOT_READ; // flags to tell PCFX whether not to read/write
volatile uint8_t  dataport = VALUE_INV_ADDR;        // pre-fetched data for fifo_to_pcfx[to_pcfx_tail]

// Maybe making these into 'int' type makes them faster ?
//
//volatile int  control  = FIFO_CTRL_DO_NOT_READ; // flags to tell PCFX whether not to read/write
//volatile int  dataport = VALUE_INV_ADDR;        // pre-fetched data for fifo_to_pcfx[to_pcfx_tail]

// debug stuff commented out
//
//volatile int      writes_to_port = 0;
//volatile int      writes_not_to_port = 0;

//volatile uint32_t write_addr[128];
//volatile int write_addr_index = 0;


// default format for a (formatted and empty) 128KB memory card
//
uint8_t formatted_bmp_00[] = {
        0x24, 0x8A, 0xDF, 0x50,  'P',  'C',  'F',  'X',   'C',  'a',  'r',  'd', 0x00, 0x01, 0x01, 0x00,
        0x01, 0xFC, 0x00, 0x00, 0x04, 0xF9, 0x0C, 0x00,  0x01, 0x00, 0x01, 0x00, 0x00, 0x00, 0x00, 0x00
};

uint8_t formatted_bmp_80[] = {
        0xF9, 0xFF, 0xFF
};


// Next line is only used for booting from Cart:
uint8_t boot_bmp_20[] = {
        0x00, 0x00, 0x00, 0x00, 0x00, 0x00, 0x00, 0x00,   'P',  'C',  'F',  'X',  'B',  'o',  'o',  't'

        // Next 16 bytes (at offset 0x0030) are 4-byte words of:
        //    source offset    (0x0400)
        //    RAM Destination  (0x8000)
        //    Transfer Size    (variable)
        //    Transfer Address (0x8000)
};




void __not_in_flash_func(to_pcfx_add_byte)(uint8_t indata)
{
int size;

   size = ((to_pcfx_head + FIFO_SIZE - to_pcfx_tail) & FIFO_SIZE_MASK);

   if (size < FIFO_SIZE_MASK) {
      fifo_to_pcfx[to_pcfx_head] = indata;
      to_pcfx_head = ((to_pcfx_head + 1) & FIFO_SIZE_MASK);
   }

   dataport = fifo_to_pcfx[to_pcfx_tail];
   control &= ~FIFO_CTRL_DO_NOT_READ;
}

uint8_t __not_in_flash_func(to_pcfx_consume_byte)(void)
{
uint8_t data;

   if (to_pcfx_tail == to_pcfx_head) {    // empty FIFO
      data = VALUE_INV_ADDR;
      control |= FIFO_CTRL_DO_NOT_READ;
   }
   else {
      data = fifo_to_pcfx[to_pcfx_tail];
      to_pcfx_tail = ((to_pcfx_tail + 1) & FIFO_SIZE_MASK);

      if (to_pcfx_tail == to_pcfx_head)   // did we drain the FIFO completely ?
      {                                   // pre-setup next values
         dataport = VALUE_INV_ADDR;
         control |= FIFO_CTRL_DO_NOT_READ;
      } else {
         dataport = fifo_to_pcfx[to_pcfx_tail];
         control &= ~FIFO_CTRL_DO_NOT_READ;
      }
   }
   return(data);
}


void __not_in_flash_func(from_pcfx_add_byte)(uint8_t indata)
{
int size;

   size = ((from_pcfx_head + 1024 - from_pcfx_tail) & FIFO_SIZE_MASK);

   if (size < FIFO_SIZE_MASK) {
      fifo_from_pcfx[from_pcfx_head] = indata;
      from_pcfx_head = ((from_pcfx_head + 1) & FIFO_SIZE_MASK);
   }

   if ((size + 1) == FIFO_SIZE_MASK)
      control |= FIFO_CTRL_DO_NOT_WRITE;
   else
      control &= ~FIFO_CTRL_DO_NOT_WRITE;
}

uint8_t __not_in_flash_func(from_pcfx_consume_byte)(void)
{
uint8_t data;

   if (from_pcfx_tail == from_pcfx_head) {
      data = VALUE_INV_ADDR;
   }
   else {
      data = fifo_from_pcfx[from_pcfx_tail];
      from_pcfx_tail = ((from_pcfx_tail + 1) & FIFO_SIZE_MASK);
   }
   control &= ~FIFO_CTRL_DO_NOT_WRITE;
   return(data);
}

void __not_in_flash_func(out_str)(char * string)
{
   for (int i = 0; i < strlen(string); i++) {
      putchar_raw( *(string+i) );
   }
   putchar_raw(0x0D);
   putchar_raw(0x0A);
}

//
// Deal with bus access to Pseudo-RAM
//
static void __not_in_flash_func(core1_entry)(void)
{
uint8_t indata;
uint32_t bus_address;
uint32_t bus;

    while (1)
    {
       bus = gpio_get_all();

       if ((bus & READ_BITMASK) == 0)   // bus reads from memory
       {
          bus_address = ((bus & GPIO_MASK_ADDR) >> GPIO_ADDR_SHIFT);

          if (bus_address < GPIO_ADDR_THRESH) {
             gpio_put_masked(GPIO_MASK_DATA, mem_array[bus_address]);
          }
          else switch(bus_address)
          {
             case GPIO_PORT_DATA:
                gpio_put_masked(GPIO_MASK_DATA, dataport);
                break;

             case GPIO_PORT_CONTROL:
                gpio_put_masked(GPIO_MASK_DATA, control);
                break;

             default:
                gpio_put_masked(GPIO_MASK_DATA, VALUE_INV_ADDR);
                break;
          }
          gpio_set_dir_masked(GPIO_MASK_DATA, 0xFF);
          while (!gpio_get(OE_PIN) );
          gpio_set_dir_masked(GPIO_MASK_DATA, 0x00);

          if (bus_address == GPIO_PORT_DATA) {
             indata = to_pcfx_consume_byte();  // throwaway
          }
       }

       if ((bus & WRITE_BITMASK) == 0)   // bus writes to memory
       {
          bus_address = ((bus & GPIO_MASK_ADDR) >> GPIO_ADDR_SHIFT);

          // Read again, as data is not guaranteed to be correct until
          // slightly after the /WE pin goes low.
          //
          indata = (gpio_get_all() & GPIO_MASK_DATA);

// debug logging
//          write_addr[write_addr_index] = bus_address;
//          write_addr_index = write_addr_index + 1;

          if (bus_address < GPIO_ADDR_THRESH) {
             mem_array[bus_address] = indata;
          }
          else switch(bus_address) {
             case GPIO_PORT_DATA:
                from_pcfx_add_byte(indata);
//                writes_to_port++;
                break;

             default:
//                writes_not_to_port++;
                break;
          }
          while (!gpio_get(WE_PIN) );
       }
//sprintf(buf, "addr %6.6X", bus_address);
//out_str(buf);

    }
}



/// UART
//
uint8_t __not_in_flash_func(uart_get_char)(void)
{
int inchar;

   inchar = getchar_timeout_us(0);

   while (inchar == PICO_ERROR_TIMEOUT)
      inchar = getchar_timeout_us(0);

   return((uint8_t)inchar);
}


uint8_t __not_in_flash_func(uart_get_cmd)(void)
{
uint8_t  uart_byte = 0;
bool     word_match = false;

   while (!word_match)
   {
     uart_byte = uart_get_char();

     if ((uart_byte == CMD_DUMP) ||
         (uart_byte == CMD_DUMPALL) ||
         (uart_byte == CMD_GETFIFO) ||
         (uart_byte == CMD_WRITE128K) ||
         (uart_byte == CMD_READ128K) ||
         (uart_byte == CMD_BOOT) ||
         (uart_byte == CMD_BOOT_BLOCK_CONT) ||
         (uart_byte == CMD_BOOT_BLOCK_FINAL))
     {
        word_match = true;
     }
   }
   return(uart_byte);
}

uint32_t __not_in_flash_func(uart_get_word)(void)
{
uint32_t uart_word = 0;

   uart_word = uart_get_char();
   uart_word |= (uart_get_char() << 8);
   uart_word |= (uart_get_char() << 16);
   uart_word |= (uart_get_char() << 24);

   return(uart_word);
}

uint32_t __not_in_flash_func(get_word)(uint32_t offset)
{
uint32_t value;
   value  = mem_array[offset];
   value |= (mem_array[offset+1] << 8);
   value |= (mem_array[offset+2] << 16);
   value |= (mem_array[offset+3] << 24);
   return(value);
}

void __not_in_flash_func(put_word)(uint32_t offset, uint32_t value)
{
   mem_array[offset]   = (value & 0xff);
   mem_array[offset+1] = ((value>>8) & 0xff);
   mem_array[offset+2] = ((value>>16) & 0xff);
   mem_array[offset+3] = ((value>>24) & 0xff);
}

void __not_in_flash_func(get_cmd_from_uart)(void)
{
uint8_t fx_command;
uint8_t uart_byte;
char buf[256];
uint32_t i, j, k;
uint32_t data_length;
uint32_t new_load_addr;
uint32_t queue_depth;

    fx_command = uart_get_cmd();

    if (fx_command == CMD_DUMP) {
       for (i = 0; i < 16; i++) {
          sprintf(buf, "%6.6X:", (i*16));
          for (k = 0; k < strlen(buf); k++) {
             putchar_raw(buf[k]);
          }
          for (j = 0; j < 16; j++) {
             sprintf(buf, " %2.2X", mem_array[(i*16) + j]);
             for (k = 0; k < strlen(buf); k++) {
                putchar_raw(buf[k]);
             }
          }
          putchar_raw(0x0D);
          putchar_raw(0x0A);
       }
       putchar_raw(0x0D);
       putchar_raw(0x0A);
       
    }

    else if (fx_command == CMD_DUMPALL) {
       for (i = 0; i < 1025; i++) {
          sprintf(buf, "%6.6X:", (i*16));
          for (k = 0; k < strlen(buf); k++) {
             putchar_raw(buf[k]);
          }
          for (j = 0; j < 16; j++) {
             sprintf(buf, " %2.2X", mem_array[(i*16) + j]);
             for (k = 0; k < strlen(buf); k++) {
                putchar_raw(buf[k]);
             }
          }
          putchar_raw(0x0D);
          putchar_raw(0x0A);
       }
       putchar_raw(0x0D);
       putchar_raw(0x0A);
    }
       
    else if (fx_command == CMD_GETFIFO) {

#ifdef TEST_BUILD
       sprintf(buf, "tail = %d, head = %d", from_pcfx_tail, from_pcfx_head);
       for (k = 0; k < strlen(buf); k++) {
          putchar_raw(buf[k]);
       }
       putchar_raw(0x0D);
       putchar_raw(0x0A);
#endif

       queue_depth = ((from_pcfx_head + FIFO_SIZE - from_pcfx_tail) & FIFO_SIZE_MASK);
       putchar_raw(queue_depth & 0xFF);
       putchar_raw((queue_depth>>8) & 0xFF);

       while (queue_depth > 0) {
          putchar_raw(from_pcfx_consume_byte());
          queue_depth--;
       }
    }

    else if (fx_command == CMD_WRITE128K) {
       for (i = 0; i < ARRAY_SIZE; i++) {
          mem_array[i] = uart_get_char();
       }
    }

    else if (fx_command == CMD_READ128K) {
       for (i = 0; i < ARRAY_SIZE; i++) {
          putchar_raw(mem_array[i]);
       }
    }

    else if (fx_command == CMD_BOOT) {
       data_length = uart_get_word();

       for (i = 0; i < data_length; i++) {
          mem_array[CODE_BMP_OFFSET + i] = uart_get_char();
       }
       for (i = 0; i < 16; i++) {
          mem_array[0x0020 + i] = boot_bmp_20[i];
       }
       put_word(FX_BOOT_OFFSET, CODE_BMP_OFFSET);
       put_word(FX_BOOT_LOADADDR, FX_EXECUTION_ADDR);
       put_word(FX_BOOT_NUMBYTES, data_length);
       put_word(FX_BOOT_EXEC, FX_EXECUTION_ADDR);
       mem_array[FX_CONFIRMATION] = FX_WRITE_DONE;     // message that transfer is complete (but more is coming)
    }

    else if (fx_command == CMD_BOOT_BLOCK_CONT) {
       data_length = uart_get_word();

       for (i = 0; i < data_length; i++) {
          mem_array[CODE_BMP_OFFSET + i] = uart_get_char();
       }
       for (i = 0; i < 16; i++) {
          mem_array[0x0020 + i] = boot_bmp_20[i];
       }
       new_load_addr = get_word(FX_BOOT_LOADADDR) + get_word(FX_BOOT_NUMBYTES); // previous FX target addr + length
       put_word(FX_BOOT_OFFSET, CODE_BMP_OFFSET);
       put_word(FX_BOOT_LOADADDR, new_load_addr);
       put_word(FX_BOOT_NUMBYTES, data_length);
       put_word(FX_BOOT_EXEC, FX_EXECUTION_ADDR);
       mem_array[FX_CONFIRMATION] = FX_WRITE_DONE;     // message that transfer is complete (but more is coming)
    }

    else if (fx_command == CMD_BOOT_BLOCK_FINAL) {
       data_length = uart_get_word();

       for (i = 0; i < data_length; i++) {
          mem_array[CODE_BMP_OFFSET + i] = uart_get_char();
       }
       for (i = 0; i < 16; i++) {
          mem_array[0x0020 + i] = boot_bmp_20[i];
       }
       new_load_addr = get_word(FX_BOOT_LOADADDR) + get_word(FX_BOOT_NUMBYTES); // previous FX target addr + length
       put_word(FX_BOOT_OFFSET, CODE_BMP_OFFSET);
       put_word(FX_BOOT_LOADADDR, new_load_addr);
       put_word(FX_BOOT_NUMBYTES, data_length);
       put_word(FX_BOOT_EXEC, FX_EXECUTION_ADDR);
       mem_array[FX_CONFIRMATION] = FX_WRITE_FINISHED;     // message that transfer is complete (and no more will come)
    }
}


void to_pcfx_string(char * string)
{
int index = 0;

   while (*(string+index) != 0x00) {
      to_pcfx_add_byte(*(string+index));
      index++;
   }
}

void fake_from_pcfx_string(char * string)
{
int index = 0;

   while (*(string+index) != 0x00) {
      from_pcfx_add_byte(*(string+index));
      index++;
   }
}

int main() {

int a;
uint32_t outword;
int i;
bool gotclock;
char buf[100];

    stdio_init_all();

    for (i = 0; i < ARRAY_SIZE; i++) {
       mem_array[i] = 0;
    }

#ifdef TEST_BUILD
    for (i = 0; i < 32; i++) {
       mem_array[i] = formatted_bmp_00[i];
    }
    for (i = 0; i < 3; i++) {
       mem_array[0x80 + i] = formatted_bmp_80[i];
    }
#endif


//// UART
    // Set up our UART with the required speed.
    uart_init(UART_ID, BAUD_RATE);
    uart_set_translate_crlf(UART_ID, false);

    // Set the TX and RX pins by using the function select on the GPIO
    // Set datasheet for more information on function select
//    gpio_set_function(UART_TX_PIN, GPIO_FUNC_UART);
//    gpio_set_function(UART_RX_PIN, GPIO_FUNC_UART);
////

//////////////////////////////////////

    gpio_init(CE_PIN);
    gpio_pull_up(CE_PIN);
    gpio_put(CE_PIN, 1);
    gpio_set_dir(CE_PIN, GPIO_IN);

    gpio_init(OE_PIN);
    gpio_pull_up(OE_PIN);
    gpio_put(OE_PIN, 1);
    gpio_set_dir(OE_PIN, GPIO_IN);

    gpio_init(WE_PIN);
    gpio_pull_up(WE_PIN);
    gpio_put(WE_PIN, 1);
    gpio_set_dir(WE_PIN, GPIO_IN);

// Data GPIOs - initially input
//
    for (int gpio = 0; gpio < 8; gpio++) {
       gpio_init(DATA0_PIN + gpio);
       gpio_pull_up(DATA0_PIN + gpio);
       gpio_put(DATA0_PIN + gpio, 1);
       gpio_set_dir(DATA0_PIN + gpio, GPIO_IN);
    }

// Addr GPIOs
//
    for (int gpio = 0; gpio < 18; gpio++) {
       gpio_init(ADDR0_PIN + gpio);
       gpio_pull_up(ADDR0_PIN + gpio);
       gpio_put(ADDR0_PIN + gpio, 1);
       gpio_set_dir(ADDR0_PIN + gpio, GPIO_IN);
    }


    sleep_ms(500);

// Test code
#ifdef TEST_BUILD
    fake_from_pcfx_string("Hello");
    to_pcfx_string("Boo");
    to_pcfx_add_byte('B');
#endif

#ifdef TEST_BUILD
    sprintf(buf, "Array size = %d", ARRAY_SIZE);
    out_str(buf);
#endif

//TODO
//    vreg_set_voltage(VREG_VOLTAGE_1_25);
    gotclock = set_sys_clock_khz(240000, 0);

#ifdef TEST_BUILD
    if (gotclock)
       sprintf(buf, "Got 240MHz clock");
    else
       sprintf(buf, "Clock stayed at 125MHz");
    out_str(buf);
#endif
    
    multicore_launch_core1(core1_entry);

// wait at startup
//
    sleep_ms(500);

    while(1) {
      get_cmd_from_uart();
    }

    return 0;
}

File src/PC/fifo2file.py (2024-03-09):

#(c) 2024  David Shadoff
import serial
import sys
import time

# Notes:
#
# This program will pipe the FX devcart's FIFO to a file
#
#   Usage: fifo2file <output_file> [COM port]
#
#   Example:
#     python fifo2file.py fifo.txt COM3
#

if ((len(sys.argv) != 3) and (len(sys.argv) != 2)):
    print("Usage: fifo2file <output_file> [COM port]")
    exit()

ser = serial.Serial()
ser.baudrate = 115200

# Add override for windows-style COM ports.
if (len(sys.argv) == 3):
    ser.port = sys.argv[2]
else:
    ser.port = '/dev/ttyUSB0'

ser.open()

# open file initially (truncate if exists)

f = open(sys.argv[1], 'wb') 
f.close()

while True:
    ser.write(b'/')             # one-byte command to fetch FIFO contents
    ser.flush()

    size = int.from_bytes(ser.read(2), "little")
    print('size =', size)

    if (size != 0):
        f = open(sys.argv[1], 'ab') # append to the file for each set of data
        memory = ser.read(size)     # read the whole (current) blob
        f.write(memory)
        f.close()
        print(memory)
    else:
        time.sleep(1)               # wait for next fetch, only if you didn't find anything

ser.close()

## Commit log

2024-03-09 Add circuit board design
    [BOM.csv, FX-Devcart_rev_A.brd, FX-Devcart_rev_A.sch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]
2024-10-02 Fix access for FIFO port addresses; allow compile on SDK2.0.0
    [main.c]
2024-10-20 Update PC Board files for new version
    [bom.csv, positions.csv]
2024-11-10 Update position of USB-C connector, and add STEP file
2024-11-18 Add enclosure (currently in prototype/validation stage)
    [FXDev_Case.scad, FX_Dev_Bottom.stl, FX_Dev_Top.stl]
2024-11-28 Minor adjustment to screw hole radii
    [FXDev_Case.scad, FX_Dev_Bottom.stl, FX_Dev_Top.stl]

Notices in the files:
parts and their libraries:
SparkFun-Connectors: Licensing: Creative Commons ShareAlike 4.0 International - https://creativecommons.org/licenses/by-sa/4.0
